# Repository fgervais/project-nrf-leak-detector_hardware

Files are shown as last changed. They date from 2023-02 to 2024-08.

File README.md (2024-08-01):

# Leak Detector, revision 3

Any two conductors can be connected to the screw terminals and the alarm will 
start if water shorts them out.

- [Complete Project](#complete-project)
- [PCB](#pcb)
- [Water Probe](#water-probe)
- [Power Consumption](#power-consumption)
- [Firmware](#firmware)
- [Notifications](#notifications)

## Complete Project

### Front side

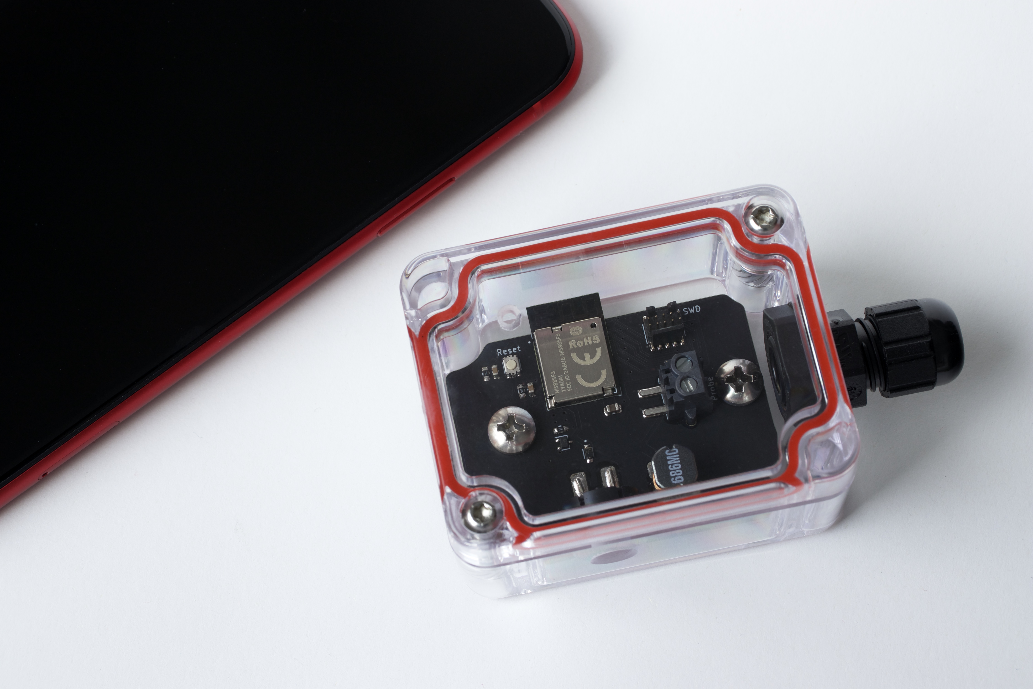
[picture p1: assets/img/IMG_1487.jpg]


### Back side

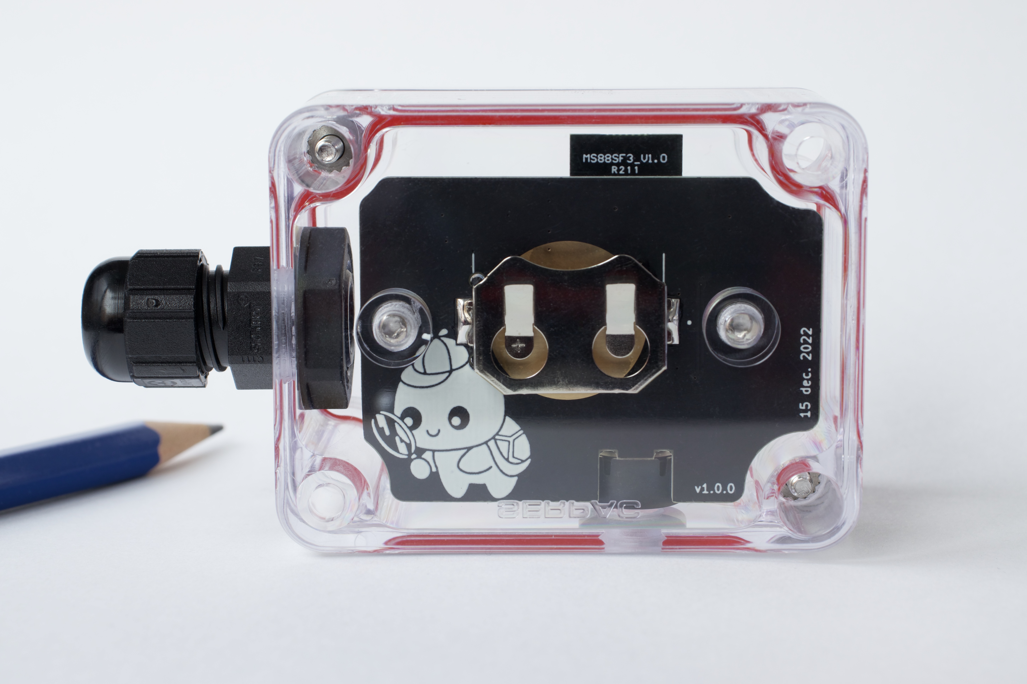
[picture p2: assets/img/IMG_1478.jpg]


## PCB

### Front side

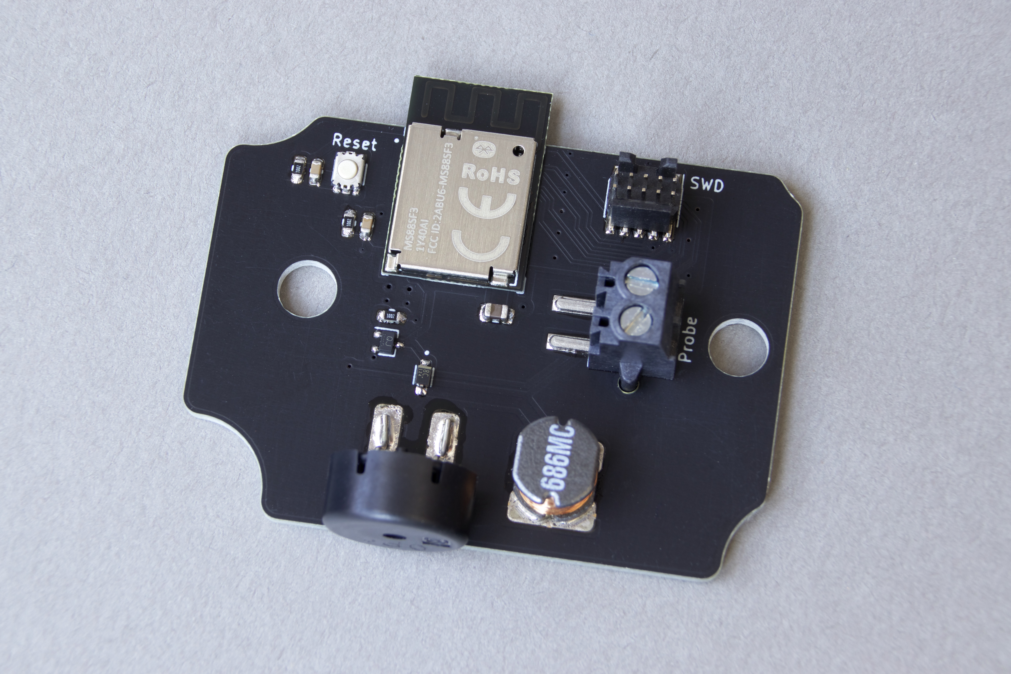
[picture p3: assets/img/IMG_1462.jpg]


### Back side

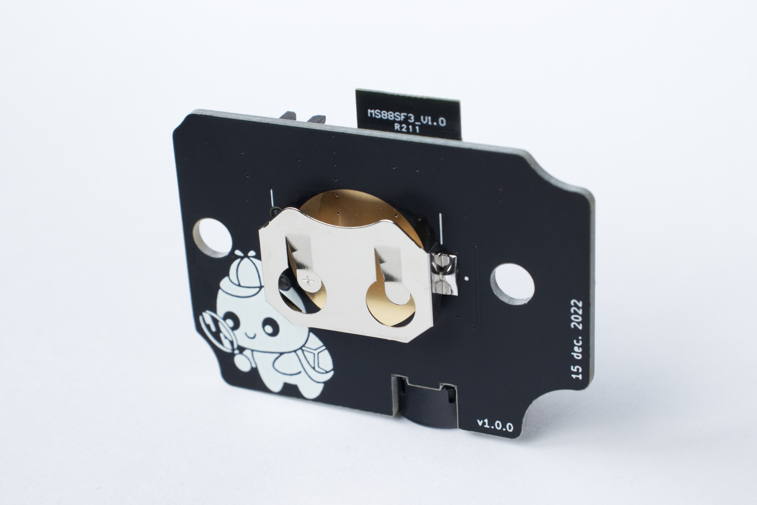
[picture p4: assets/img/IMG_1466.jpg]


## Water Probe

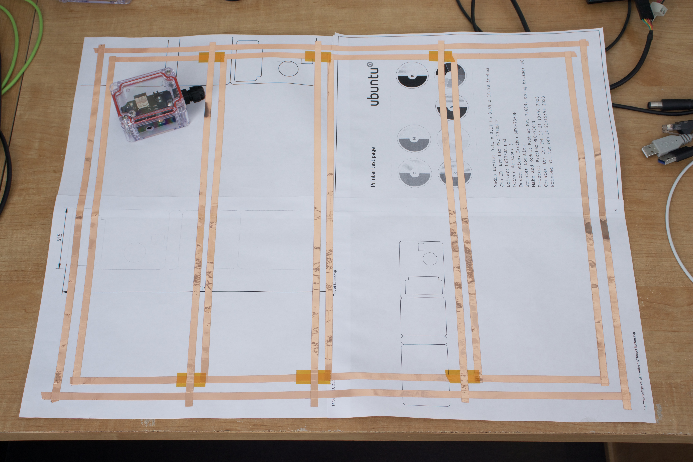
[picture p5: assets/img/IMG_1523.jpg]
Water Probe


## Power Consumption

Based on revision [`8f98e931fbc428e85092b7998ec07682605cf380`](https://github.com/fgervais/project-nrf-leak-detector/tree/8f98e931fbc428e85092b7998ec07682605cf380/app/src).

### Idle

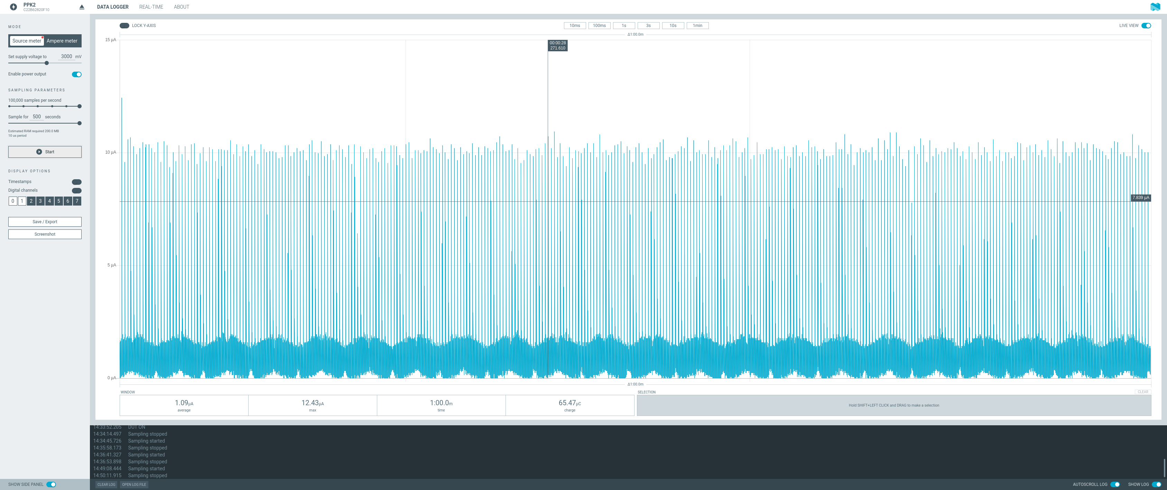
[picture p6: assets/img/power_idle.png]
Idle


How long can the device monitor for a leak?

- Energizer CR2032 = $810 \\, C$
- Idle consumption = $1.09 \\, \frac{{\mu}C}{s}$

```math
\frac{810 \, C}{1.09 \times 10^-6 \, \frac{C}{s}} = 743.119 \times 10^6 \, s
```

```math
470.93 \times 10^6 \, seconds \times \frac{1 \, minute}{60 \, second} \times \frac{1 \, hour}{60 \, minute} \times \frac{1 \, day}{24 \, hour} \times \frac{1 \, year}{365.25 \, days} = 23 \, years
```

Note: This does not account for the battery self discharge and the battery voltage
going down over time.

### Alarm

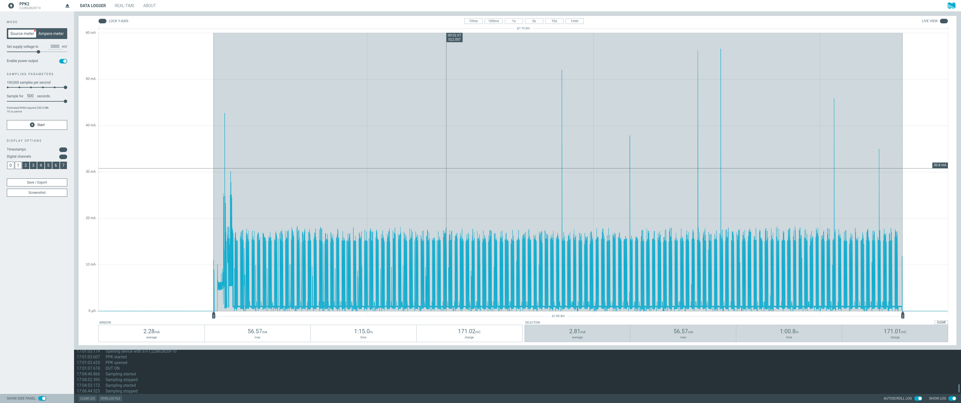
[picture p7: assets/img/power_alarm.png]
Alarm


## Firmware

https://github.com/fgervais/project-nrf-leak-detector

## Notifications

When a leak is detected, the information is sent to Home Assistant tough MQTT
which then sends a notification to computers and mobile devices.

A notification is also sent when the leak detector is reset and rearmed to let
the user know that the leak monitoring is ready.

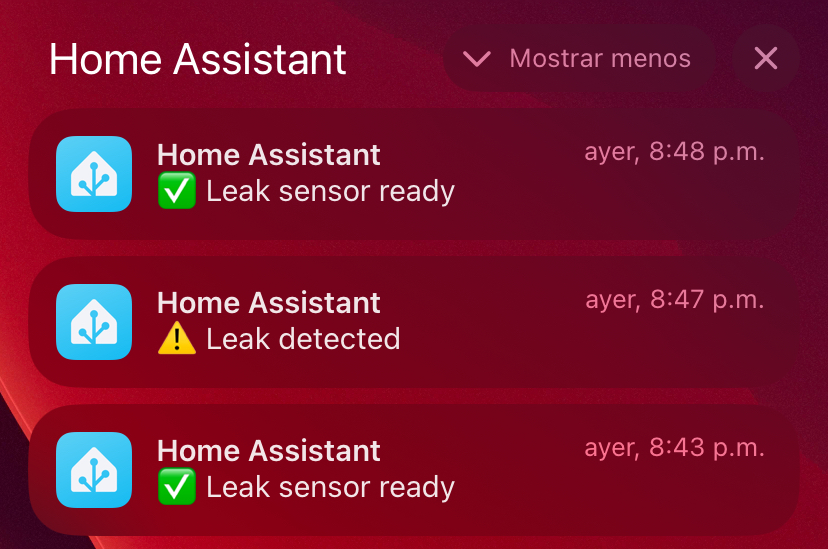
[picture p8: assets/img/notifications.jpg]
notification


### Alarm Note

The chain of events from leak detection to a nofication being delivered is
pretty long and a lot could go wrong which would prevent the notification from
being received.

Even though a lot of effort has been put in error handling and retry mechanism,
the focus is to first make sure the alarm starts without being affected by the
notification delivery process.

For this reason, the alarm is setup first before any networking work is started.
Once started, the alarm is entirely handled by the hardware PWM module and so
even if a problem happens the alarm will still be heard.

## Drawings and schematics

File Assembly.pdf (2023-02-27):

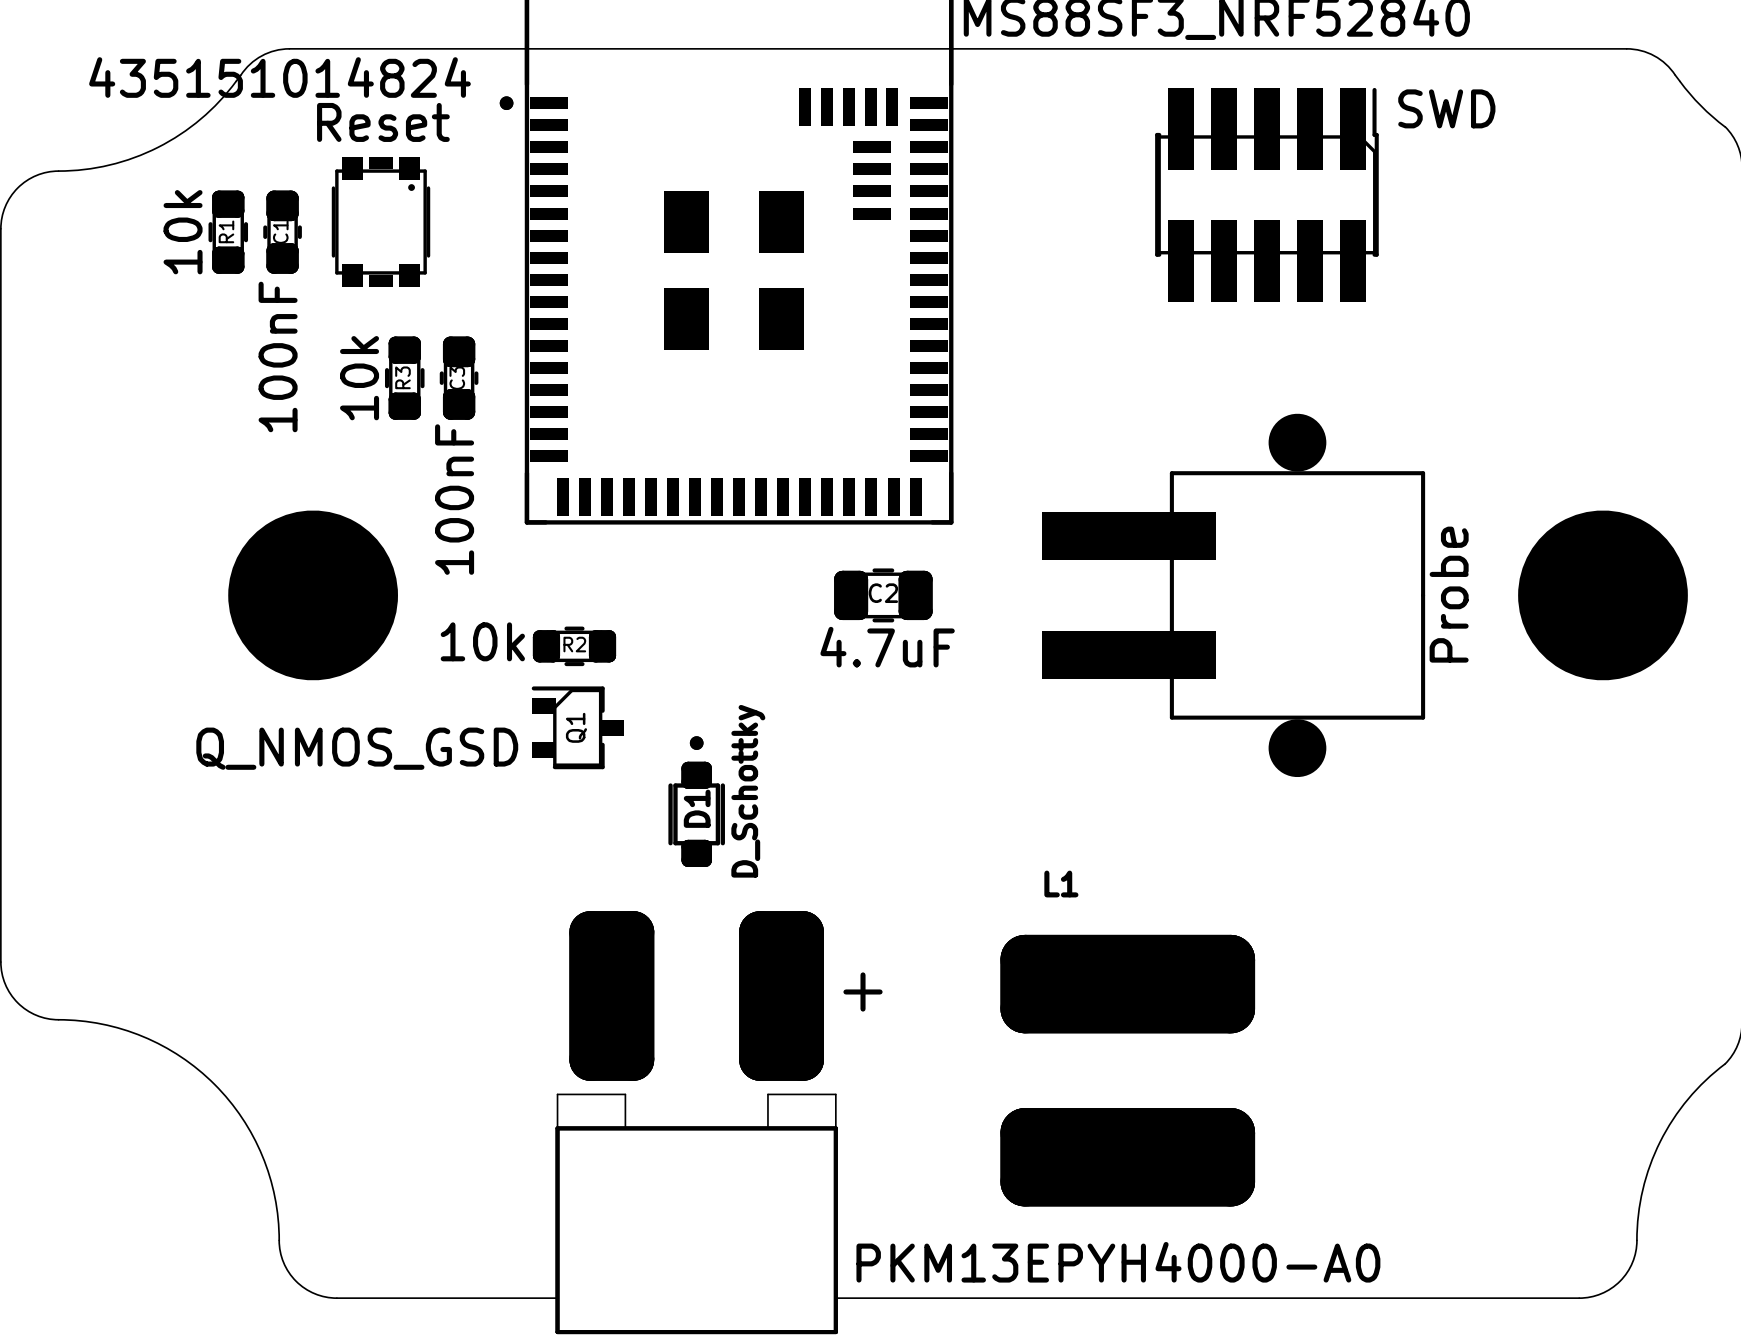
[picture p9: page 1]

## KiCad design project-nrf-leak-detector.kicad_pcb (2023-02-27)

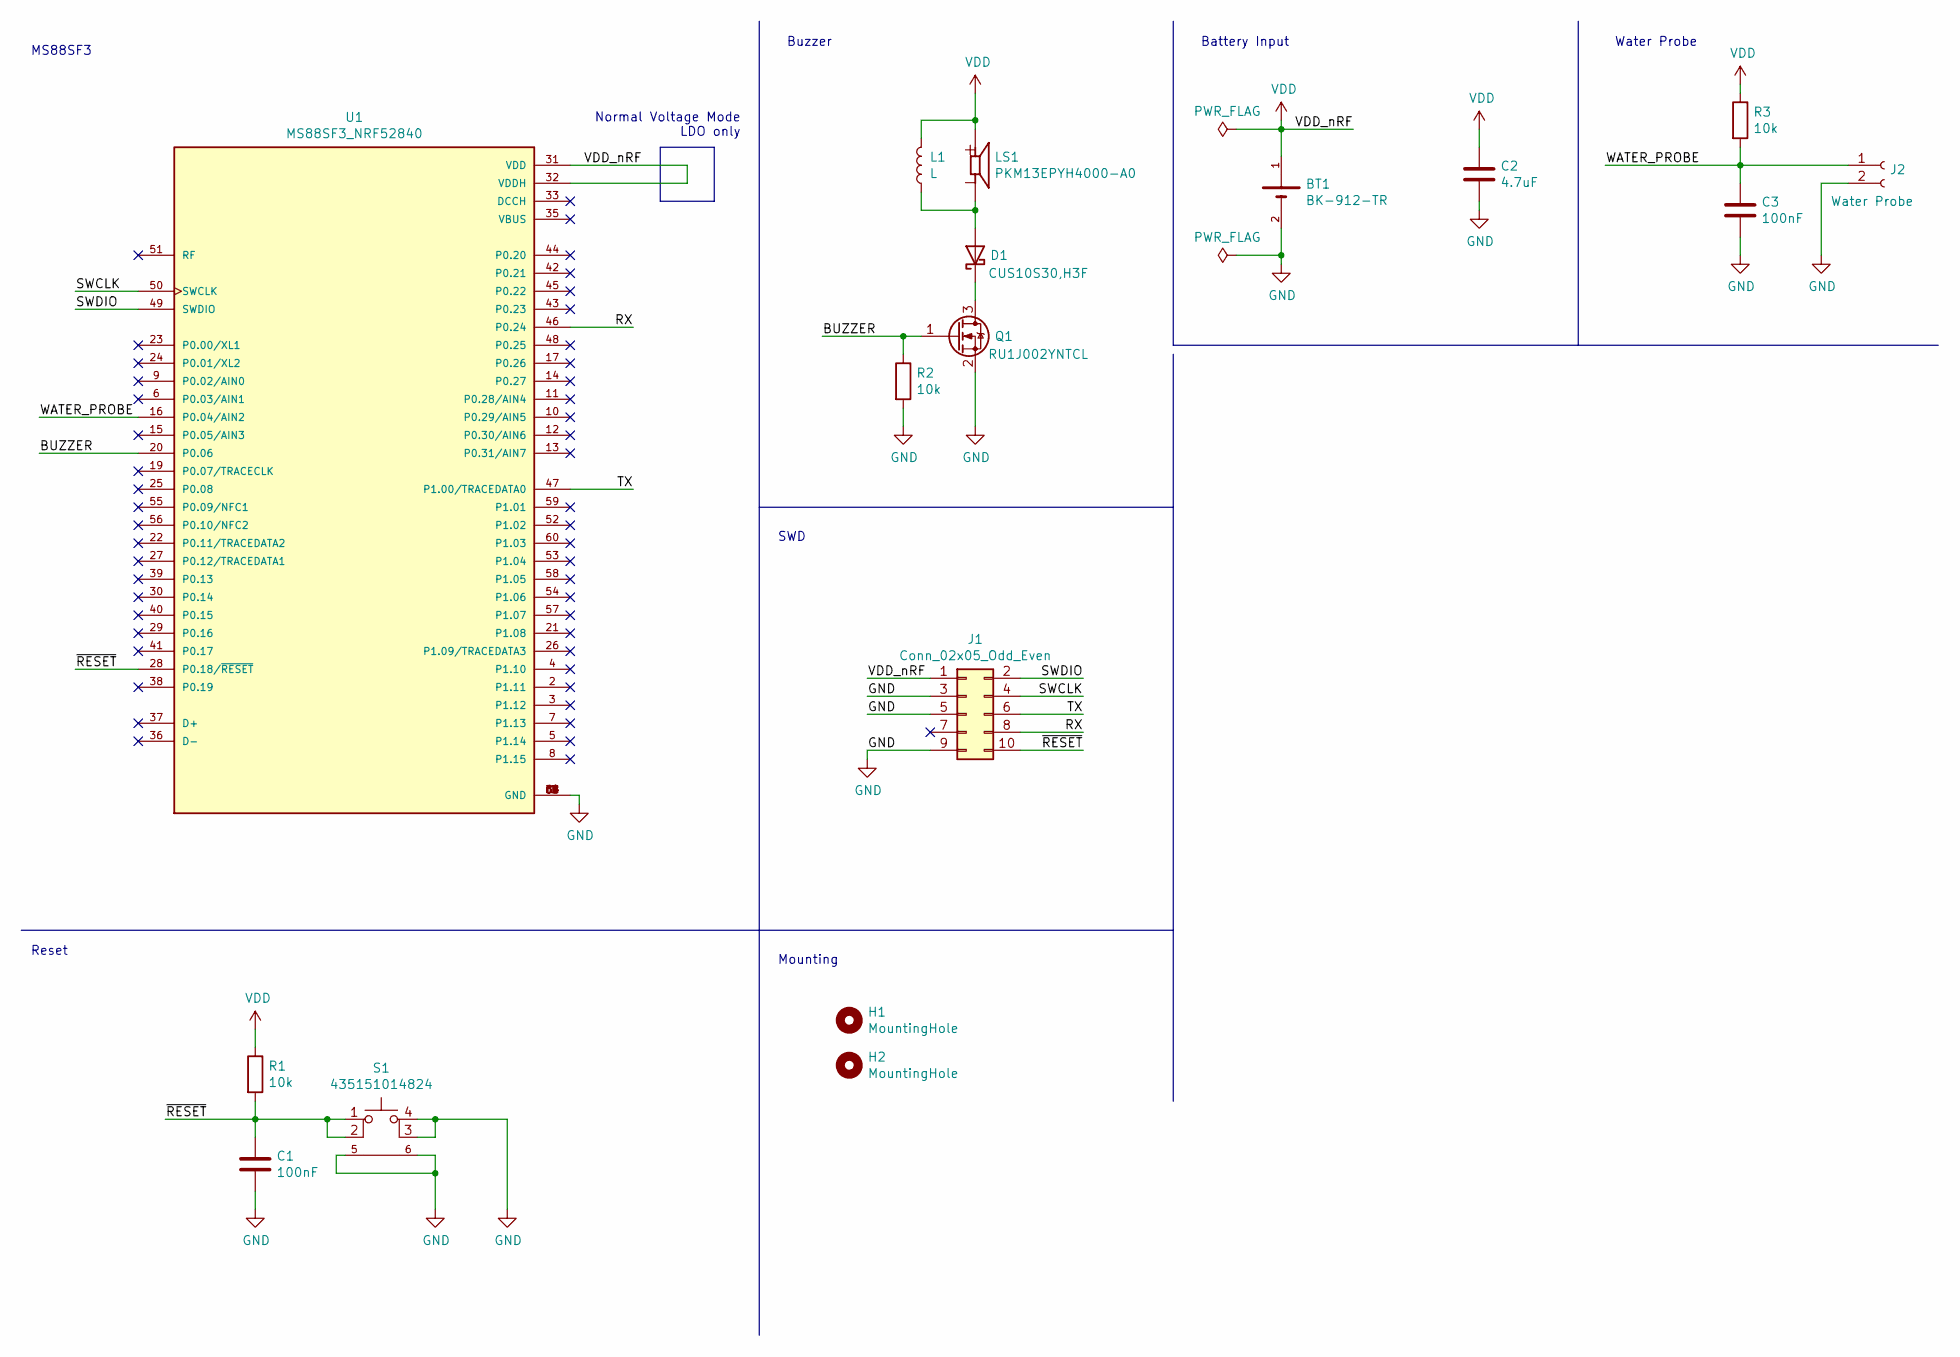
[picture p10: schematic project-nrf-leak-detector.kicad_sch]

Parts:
BT1: BK-912-TR; MPD_BK-912-TR; PARTREV H
C1, C3: 100nF; C_0603_1608Metric
C2: 4.7uF; C_0805_2012Metric
D1: D_Schottky; DIO_CUS520,H3F; MPN CUS10S30,H3F
H1, H2: MountingHole; MountingHole_5mm
J1: Conn_02x05_Odd_Even; PinHeader_2x05_P1.27mm_Vertical_SMD
J2: Water Probe; TZ022101B000G
L1: L; INDP7870X750
LS1: PKM13EPYH4000-A0; SPKR_PKM13EPYH4000-A0_SMD; PARTREV December 26, 2017
Q1: Q_NMOS_GSD; SOT-323_SC-70; MPN RU1J002YNTCL
R1, R2, R3: 10k; R_0603_1608Metric
S1: 435151014824; PART-NUMBER 435151014824
U1: MS88SF3_NRF52840; MODULE_MS88SF3_NRF52840; PARTREV V1.1

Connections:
/BUZZER: Q1.1 (G), R2.1, U1.20 (P0.06)
/RX: J1.8, U1.46 (P0.24)
/SWCLK: J1.4, U1.50 (SWCLK)
/SWDIO: J1.2, U1.49 (SWDIO)
/TX: J1.6, U1.47 (P1.00/TRACEDATA0)
/WATER_PROBE: C3.1, J2.1, R3.2, U1.16 (P0.04/AIN2)
/~RESET: C1.1, J1.10, R1.2, S1.1, S1.2, U1.28 (P0.18/~RESET)
GND: BT1.2 (-), C1.2, C2.2, C3.2, J1.3, J1.5, J1.9, J2.2, Q1.2 (S), R2.2, S1.3 (K), S1.4 (A), S1.5, S1.6, U1.1 (GND), U1.18 (GND), U1.34 (GND), U1.61 (GND), U1.62 (GND), U1.63 (GND), U1.64 (GND)
unnamed: D1.1 (K), Q1.3 (D)
unnamed: D1.2 (A), L1.1, LS1.N
VDD: BT1.1 (+), C2.1, J1.1, L1.2, LS1.P, R1.1, R3.1, U1.31 (VDD), U1.32 (VDDH)

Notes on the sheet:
Battery Input
Buzzer
Water Probe
Mounting
MS88SF3
SWD
Normal Voltage Mode LDO only
Reset

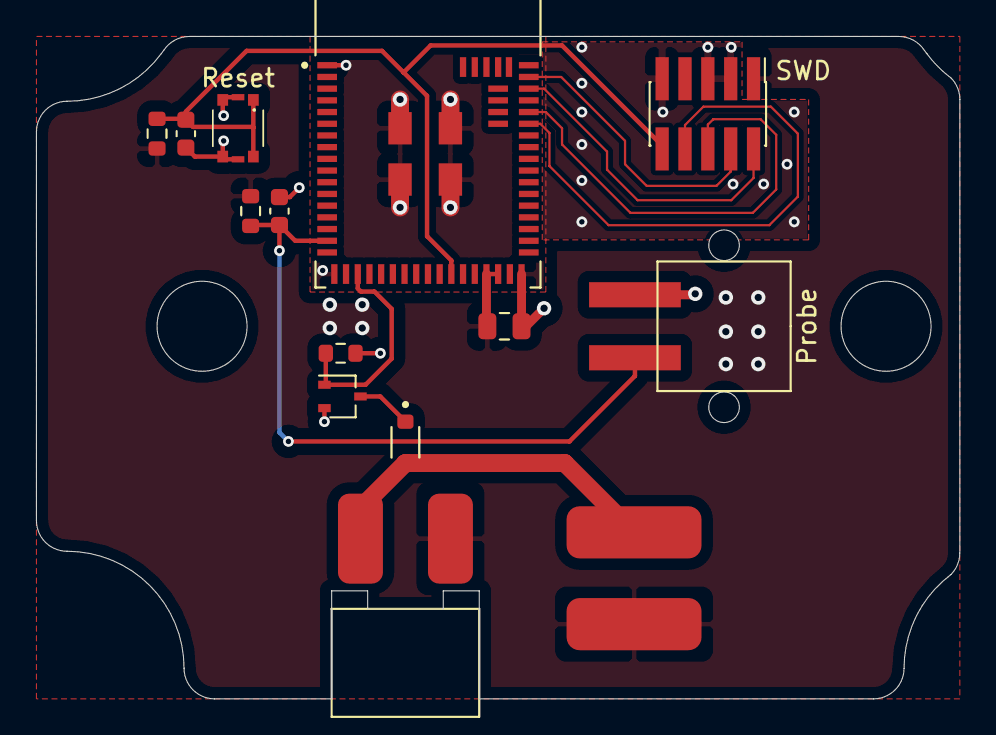
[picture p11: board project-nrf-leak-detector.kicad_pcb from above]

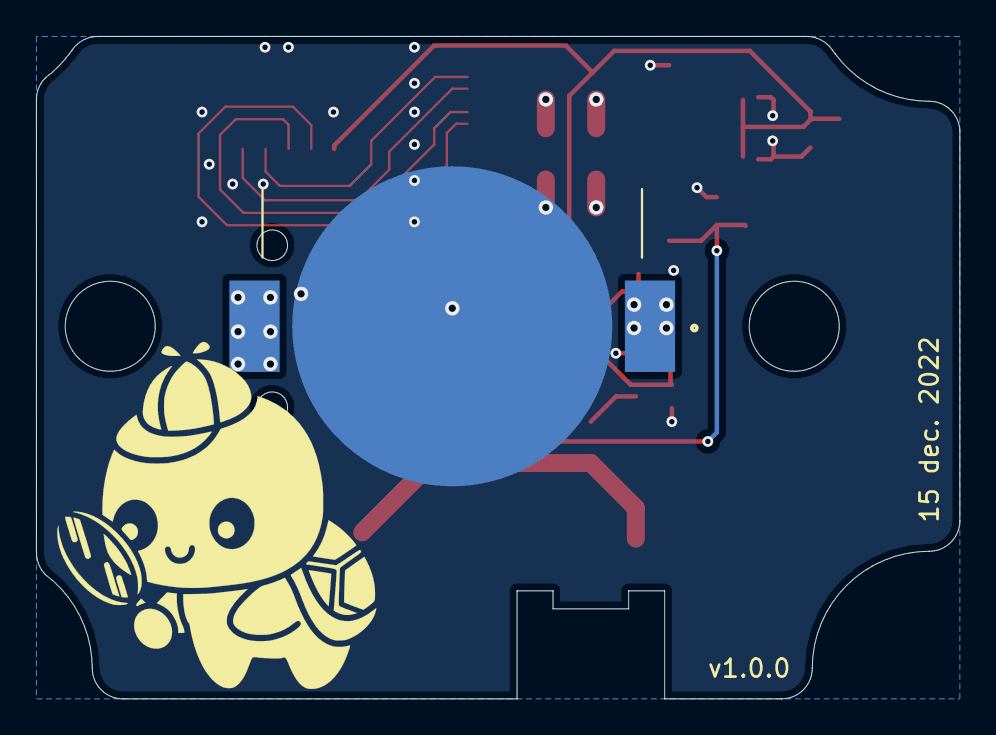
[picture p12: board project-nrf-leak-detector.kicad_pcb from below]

Board: 2 copper layers, 51.3 x 36.8 mm, 18 parts (2 on the bottom side), 11 nets.

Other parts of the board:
Ref**: Val**; turtle-01.inverted

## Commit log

2022-11-13 Add all parts to lib
    [buzzer-module.kicad_pcb, buzzer-module.sch]
2022-11-14 Remove buzzer-module
    [buzzer-module.kicad_pcb, buzzer-module.sch]
2022-11-14 Add an empty main project
    [project-nrf-leak-detector.kicad_pcb, project-nrf-leak-detector.sch]
2022-11-14 Add rough board outline
    [project-nrf-leak-detector.kicad_pcb]
2022-11-15 Imported from project-MS88SF3-breakout schematic
    [project-nrf-leak-detector.kicad_pcb, project-nrf-leak-detector.sch]
2022-11-15 Add a few more components to the schematic
    [project-nrf-leak-detector.sch]
2022-11-16 First schematic version
    [project-nrf-leak-detector.sch]
2022-11-16 Import parts to board
    [project-nrf-leak-detector.kicad_pcb, project-nrf-leak-detector.sch]
2022-11-17 First placement
    [project-nrf-leak-detector.kicad_pcb, project-nrf-leak-detector.sch]
2022-11-18 First routing
    [project-nrf-leak-detector.kicad_pcb, project-nrf-leak-detector.sch]
2022-11-18 Add a 3d model to the TZ022101B000G
    [project-nrf-leak-detector.kicad_pcb]
2022-11-21 Add info on silkscreen
    [project-nrf-leak-detector.kicad_pcb]
2022-11-25 Change RX pin to P0.24
    To avoid crossing over TX.
    [project-nrf-leak-detector.kicad_pcb, project-nrf-leak-detector.sch]
2022-11-26 Add a cap on the probe signal
    [project-nrf-leak-detector.kicad_pcb, project-nrf-leak-detector.sch]
2022-12-13 Add the turtle
    [project-nrf-leak-detector.kicad_pcb]
2022-12-15 Change the buzzer slot size and position
    [project-nrf-leak-detector.kicad_pcb]
2022-12-16 Add gerbers
    [project-nrf-leak-detector-B_Cu.gbr, project-nrf-leak-detector-B_Mask.gbr, project-nrf-leak-detector-B_Paste.gbr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]
2022-12-18 Add slot to account for routing bit radius
    [project-nrf-leak-detector.kicad_pcb]
2022-12-18 Update gerbers
    [project-nrf-leak-detector-B_Cu.gbr, project-nrf-leak-detector-B_Mask.gbr, project-nrf-leak-detector-B_Paste.gbr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]
2023-02-26 Update to KiCAD 7.0
    [project-nrf-leak-detector.kicad_pcb]
2023-02-26 Place F.Fab layer
    [project-nrf-leak-detector.kicad_pcb]
2023-02-27 Update schematic to 7.0
    [project-nrf-leak-detector.kicad_sch]
2023-02-27 Add missing part numbers
    [project-nrf-leak-detector.kicad_sch]
2023-02-27 Place F.Fab schottky and mosfet
    [project-nrf-leak-detector.kicad_pcb]
2023-02-27 Add assembly PDF
    [project-nrf-leak-detector.kicad_pcb]
2023-03-10 Add pictures of project in enclosure
2023-03-10 Add power consumption to README
2023-03-14 Correct resistor value error
    10k -> 1M
    [project-nrf-leak-detector.kicad_sch]
2023-03-25 Add the water probe image
2024-07-31 Update power consumption based on firmware v1.1.0
